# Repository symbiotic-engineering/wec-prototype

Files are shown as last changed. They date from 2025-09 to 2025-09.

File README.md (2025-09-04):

# Wave Energy Converter (WEC) Prototype Control System

## 1. Project Overview
Control system for testing **wave energy converter (WEC) prototypes** using a **Raspberry Pi touchscreen UI** and **Arduino motor control**.  
The system allows real-time interaction with prototypes, including selecting WEC type, adjusting frequency/amplitude, and running tests.

## 2. Components / Hardware
- **Raspberry Pi** – Runs the touchscreen UI  
- **Arduino Mega** – Controls the motor  
- **VESC & VESC Express** – Motor controller and Data Logger  
- **WEC prototypes** – Point Absorber and Oscillating Flap types  
- **Touchscreen** – User interface for control  

## 3. Software
- **Python** – Raspberry Pi GUI and control code (`wec_rpi_gui.py`)  
- **MATLAB** – Hydrodynamic analyses (`PA_buoyancy.m`) 
- **Arduino** – Motor control code (`wec_arduino_motorcontrol.ino`)  
- **VESC logging script** (`log_can.lisp`) – Captures motor data points  

## 4. Folder Structure 
```
WEC-Prototype/
├── Arduino_Mega/
│ └── wec_arduino_motorcontrol.ino # Arduino firmware controlling motor based on RPi commands
├── CAD/
│ └── Multiple CAD pdf files
├── Raspberry_Pi/
│ └── wec_rpi_gui.py # Python UI for controlling WEC tests
└── VESC/
└── log_can.lisp # Logs motor data points during testing
├── hydrodynamics/
  └── PA_buoyancy.m # Evaluates the hydrodynamic repsonse of the PA
├── gear_ratio_appendix/
  └── Files required to simulate both the PA and OSWEC to estimate required GR
```
## 5. Code Setup Instructions

1. **Raspberry Pi**  
   - Copy `wec_rpi_gui.py` to the Pi.  
   - Configure the script to run automatically using **cron**.  
   - Connect Raspberry Pi to Arduino via USB.  

2. **Arduino Mega**  
   - Flash `wec_arduino_motorcontrol.ino` onto the Arduino.  
   - Ensure the **VESC UART library** is downloaded from GitHub and stored in Arduino’s libraries folder.  

3. **VESC / VESC Express**  
   - Flash firmware and edit log_can.lisp to VESC and VESC Express.  

4. **Dependencies & Hardware Connections**  
   - Proper USB connection between Pi and Arduino.  
   - Ensure VESC and motor connections are secure before powering the system.  

## 6. Usage Instructions

1. Power on Raspberry Pi and Arduino.  
2. Start the Python UI (`wec_rpi_gui.py`) via touchscreen or cron.  
3. Select the WEC type (Point Absorber or Oscillating Flap).  
4. Verify that all **electrical connections** are secure.  
5. Run tests by selecting frequency/amplitude options in the UI.  
6. Data from the VESC can be logged using `log_can.lisp`.

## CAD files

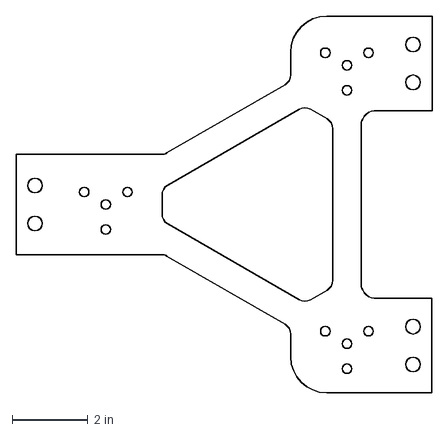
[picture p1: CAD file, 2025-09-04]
CAD/PA_BasePlate.dxf
11.0 x 9.96 in

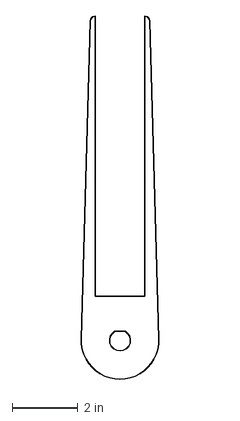
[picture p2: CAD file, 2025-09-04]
CAD/OSWEC_Struts.dxf
2.39 x 11.1 in

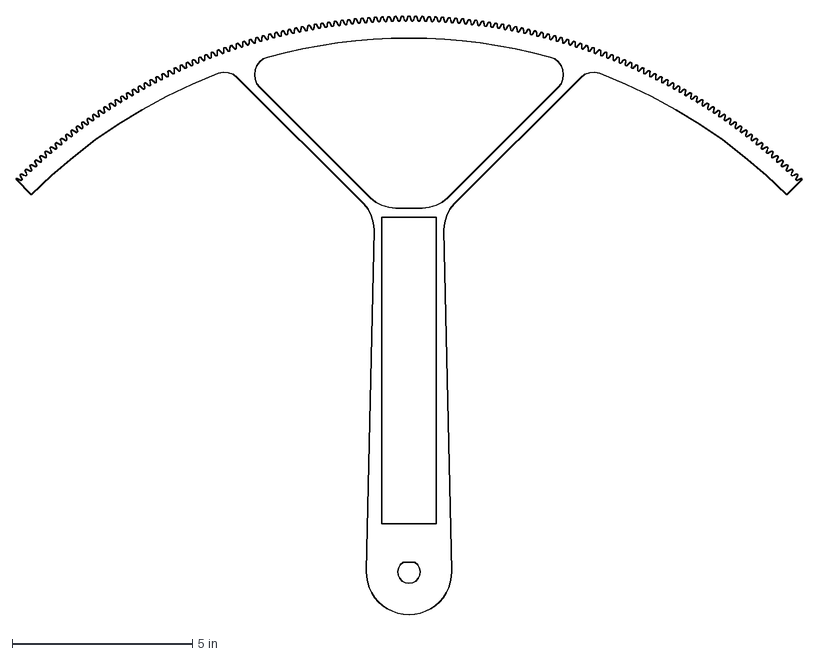
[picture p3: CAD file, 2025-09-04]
CAD/CurvedRack.dxf
21.8 x 16.6 in

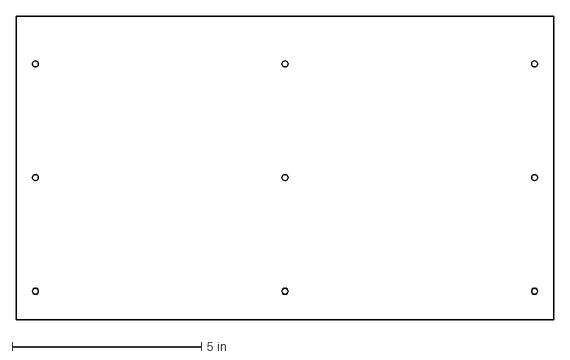
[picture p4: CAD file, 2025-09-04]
CAD/OSWEC_AcrylicPlate.dxf
14.2 x 8.00 in

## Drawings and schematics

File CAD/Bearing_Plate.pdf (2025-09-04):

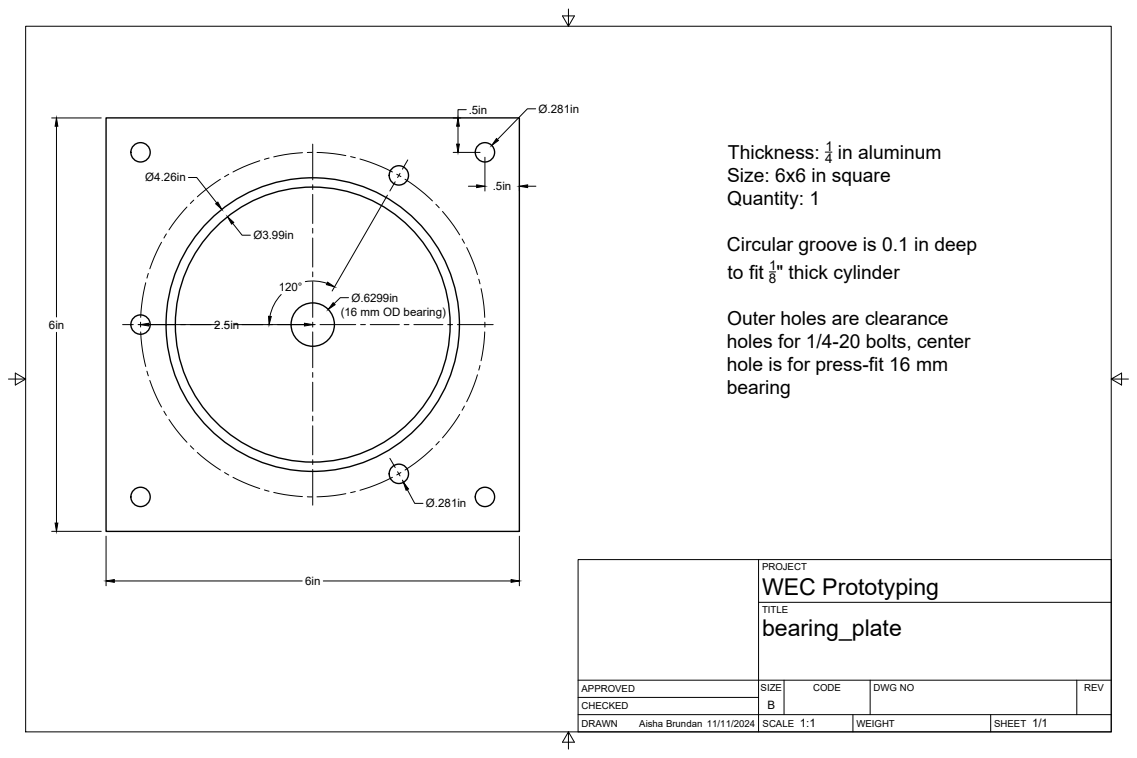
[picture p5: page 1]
SIZE; CODE; DWG NO; REV; Aisha Brundan 11/11/2024; WEC Prototyping; in aluminum

Thickness: 1
Size: 6x6 in square
Quantity: 1

Circular groove is 0.1 in deep
to fit 1
" thick cylinder

(16 mm OD bearing)

Outer holes are clearance
holes for 1/4-20 bolts, center
hole is for press-fit 16 mm
bearing

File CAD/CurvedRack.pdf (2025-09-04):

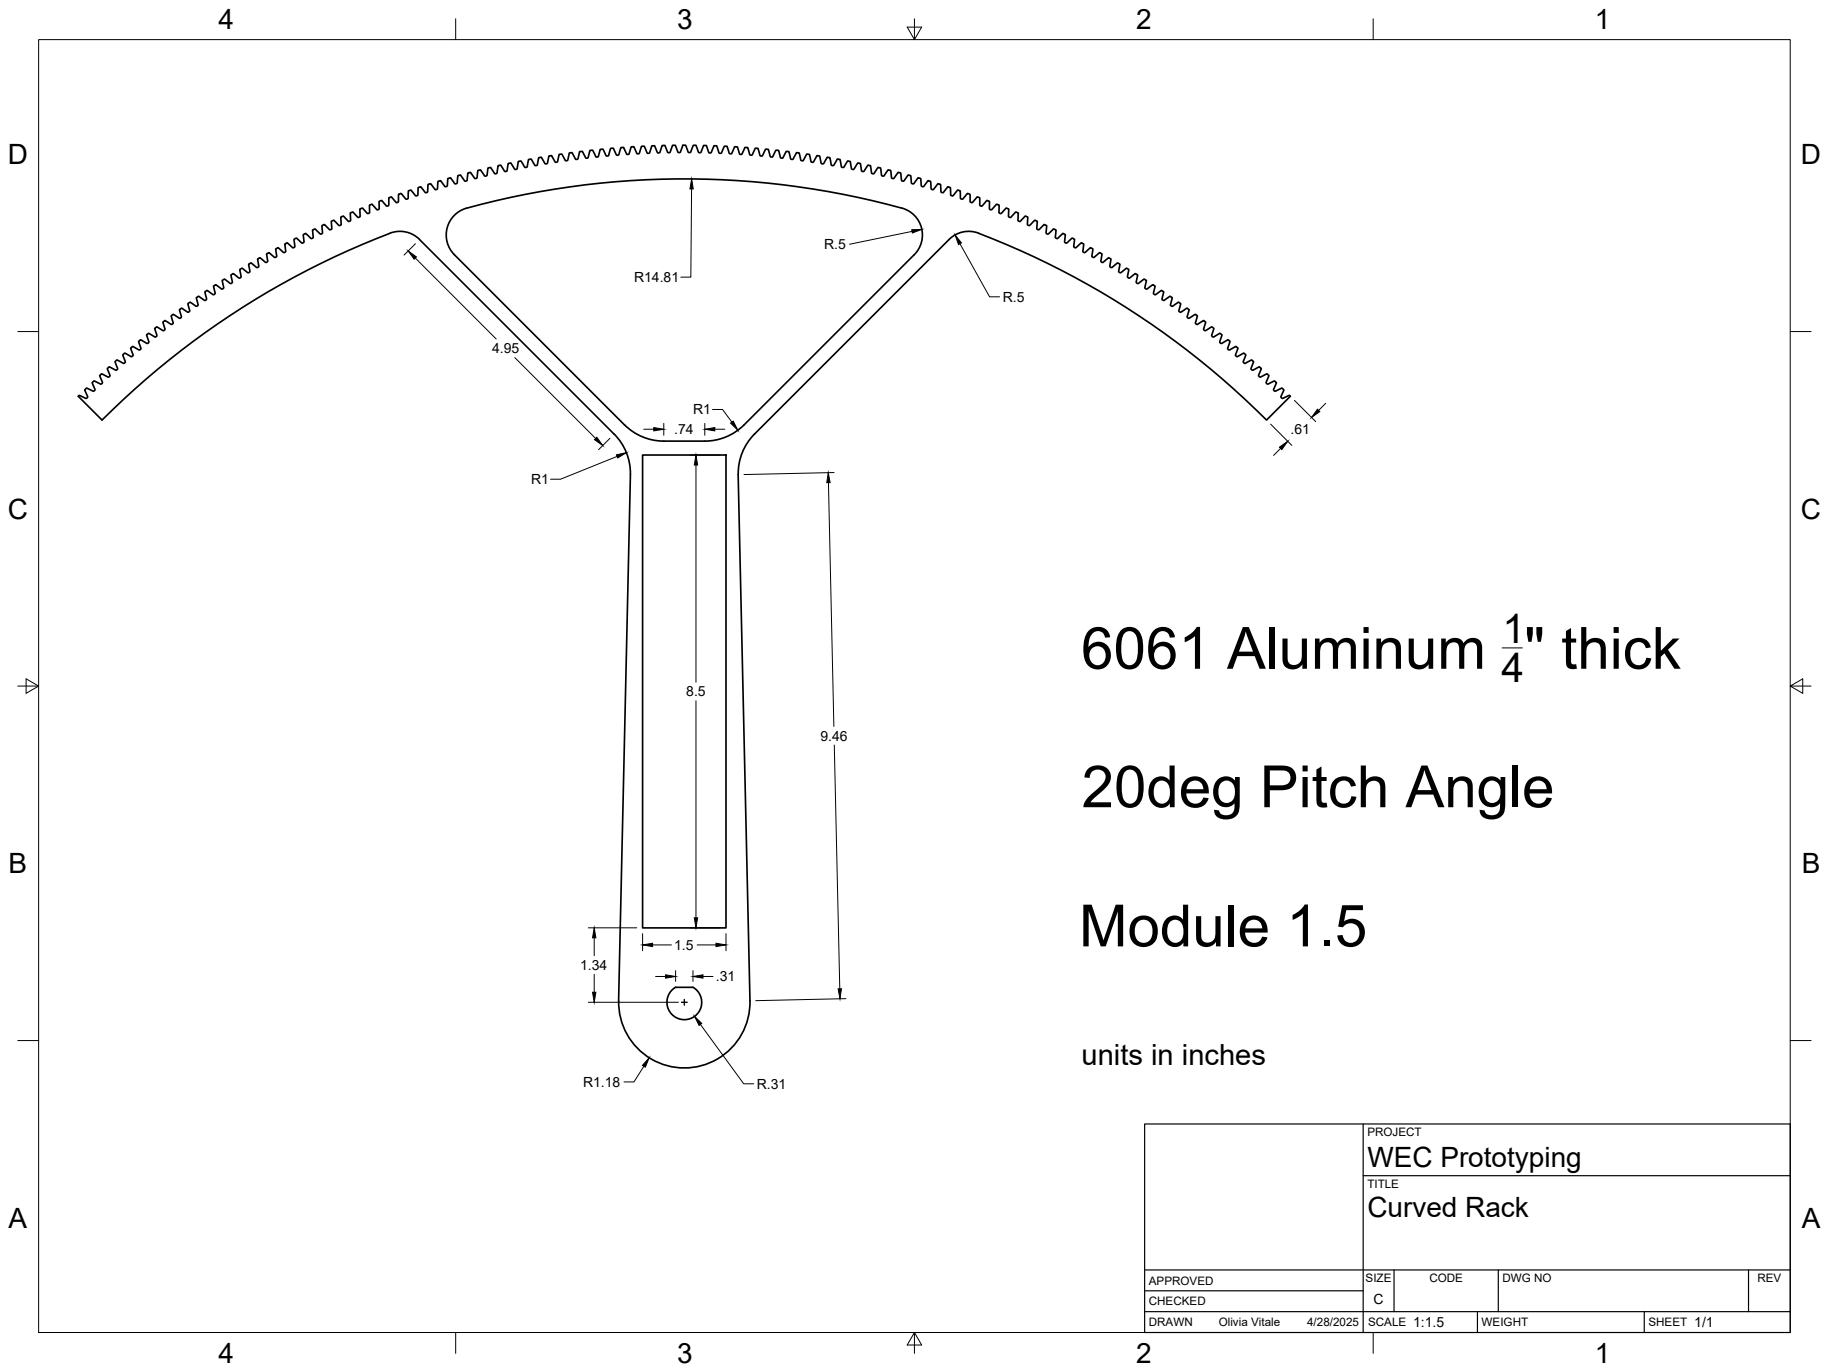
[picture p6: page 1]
SIZE; CODE; DWG NO; REV; Olivia Vitale; WEC Prototyping; Curved Rack; 6061 Aluminum 1 " thick; 20deg Pitch Angle; Module 1.5

units in inches

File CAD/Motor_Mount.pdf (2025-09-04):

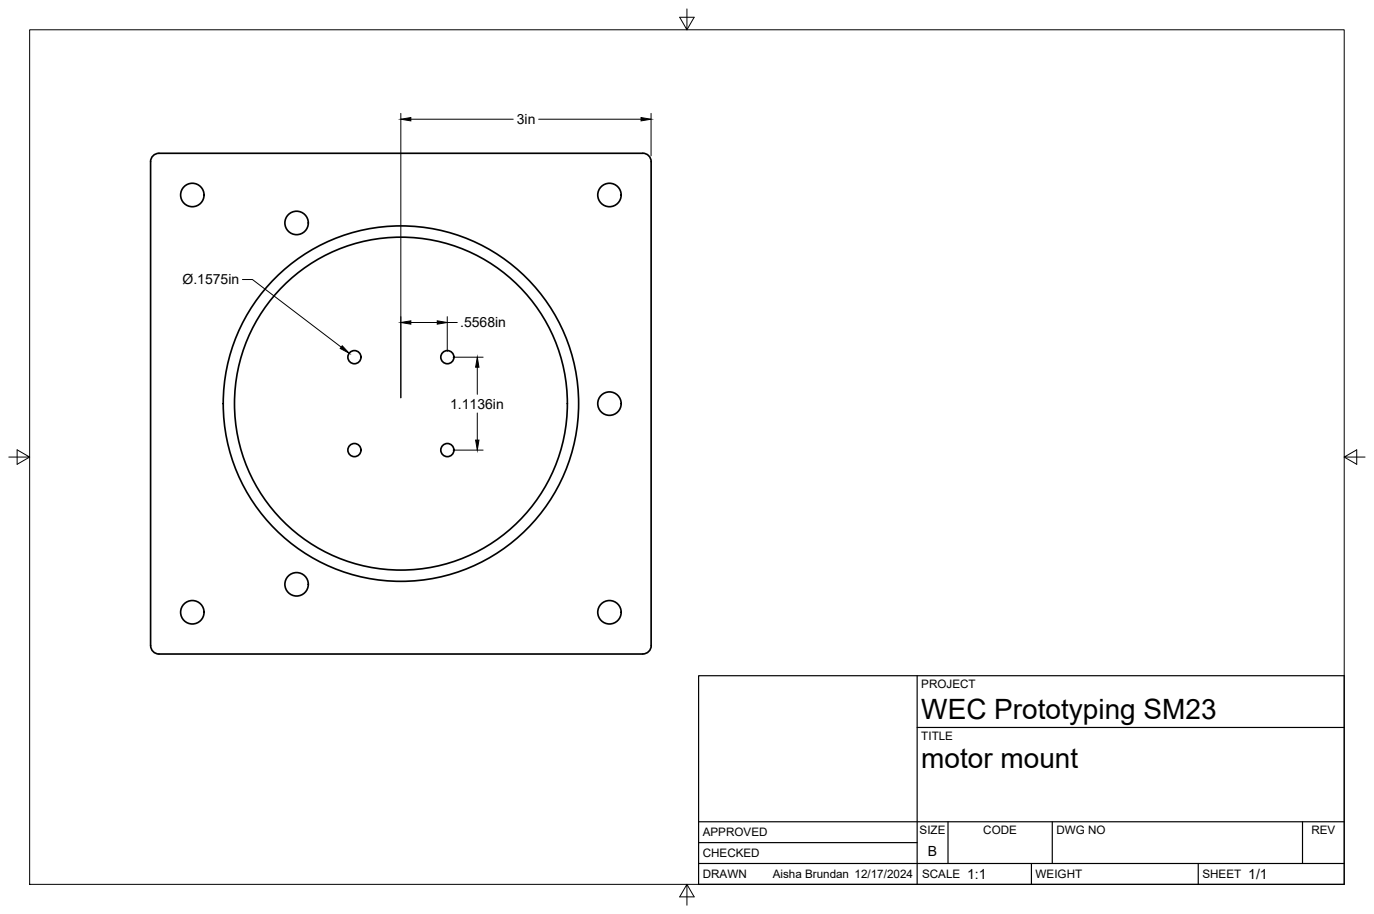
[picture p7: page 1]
SIZE; CODE; DWG NO; REV; Aisha Brundan 12/17/2024; WEC Prototyping SM23; motor mount

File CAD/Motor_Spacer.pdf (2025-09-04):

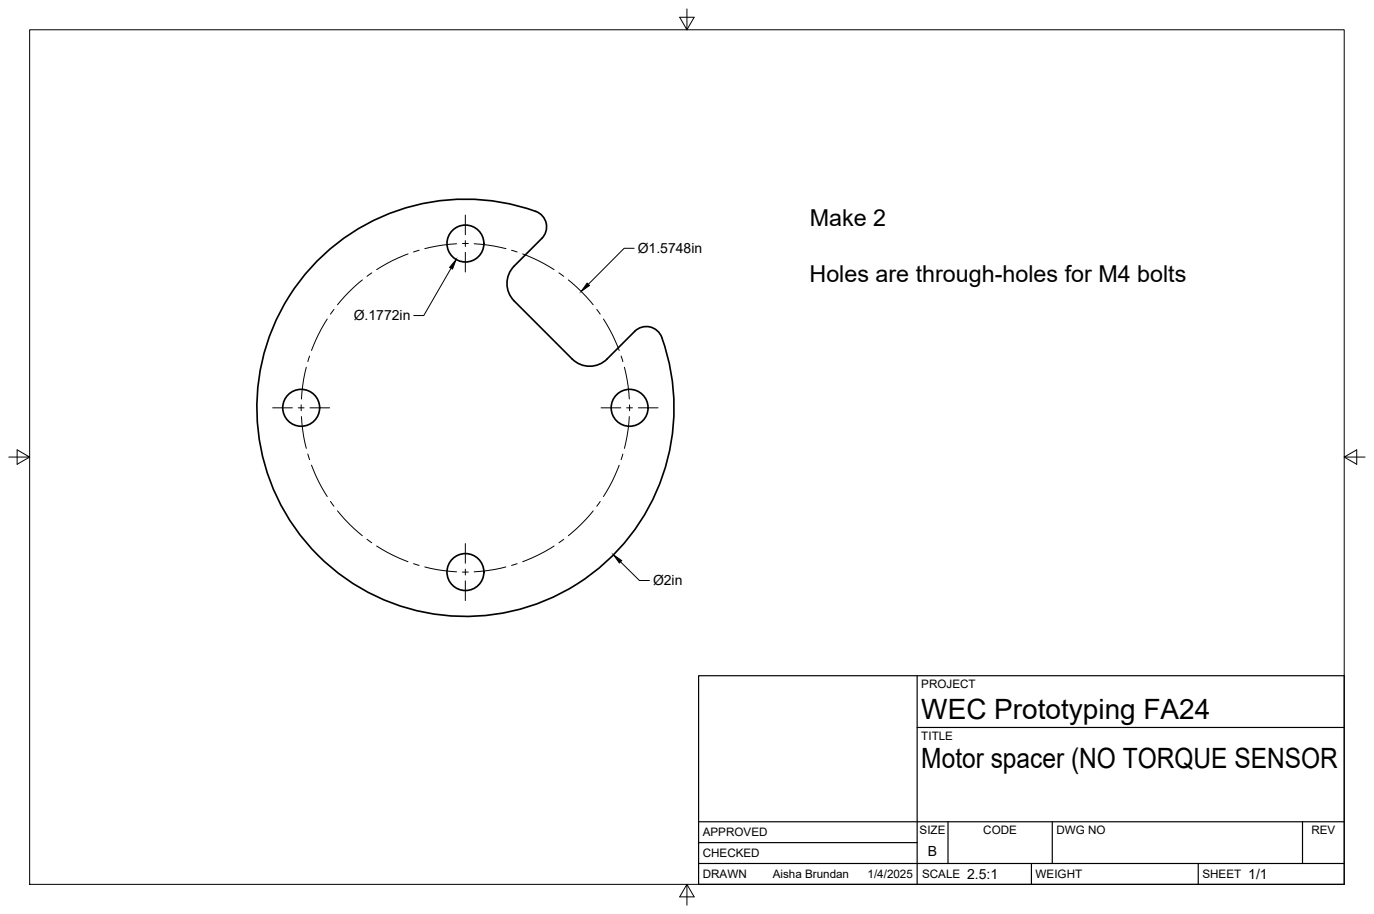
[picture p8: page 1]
SIZE; CODE; DWG NO; REV; Aisha Brundan; Make 2

Holes are through-holes for M4 bolts

PROJECT
WEC Prototyping FA24
Motor spacer (NO TORQUE SENSOR

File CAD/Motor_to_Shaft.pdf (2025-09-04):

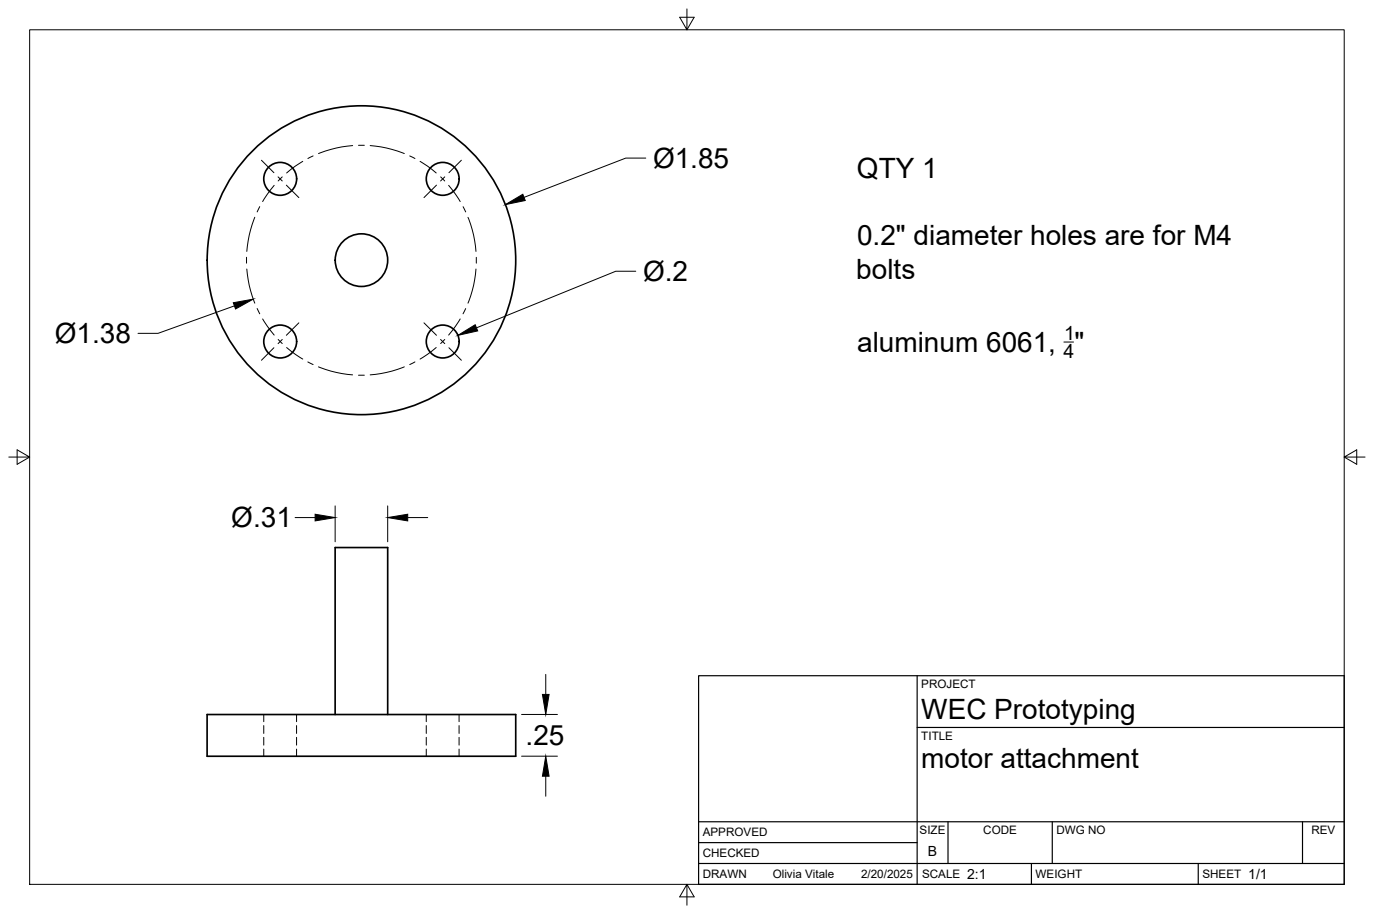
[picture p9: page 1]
SIZE; CODE; DWG NO; REV; Olivia Vitale; WEC Prototyping; motor attachment; QTY 1; aluminum 6061, 1

0.2" diameter holes are for M4
bolts

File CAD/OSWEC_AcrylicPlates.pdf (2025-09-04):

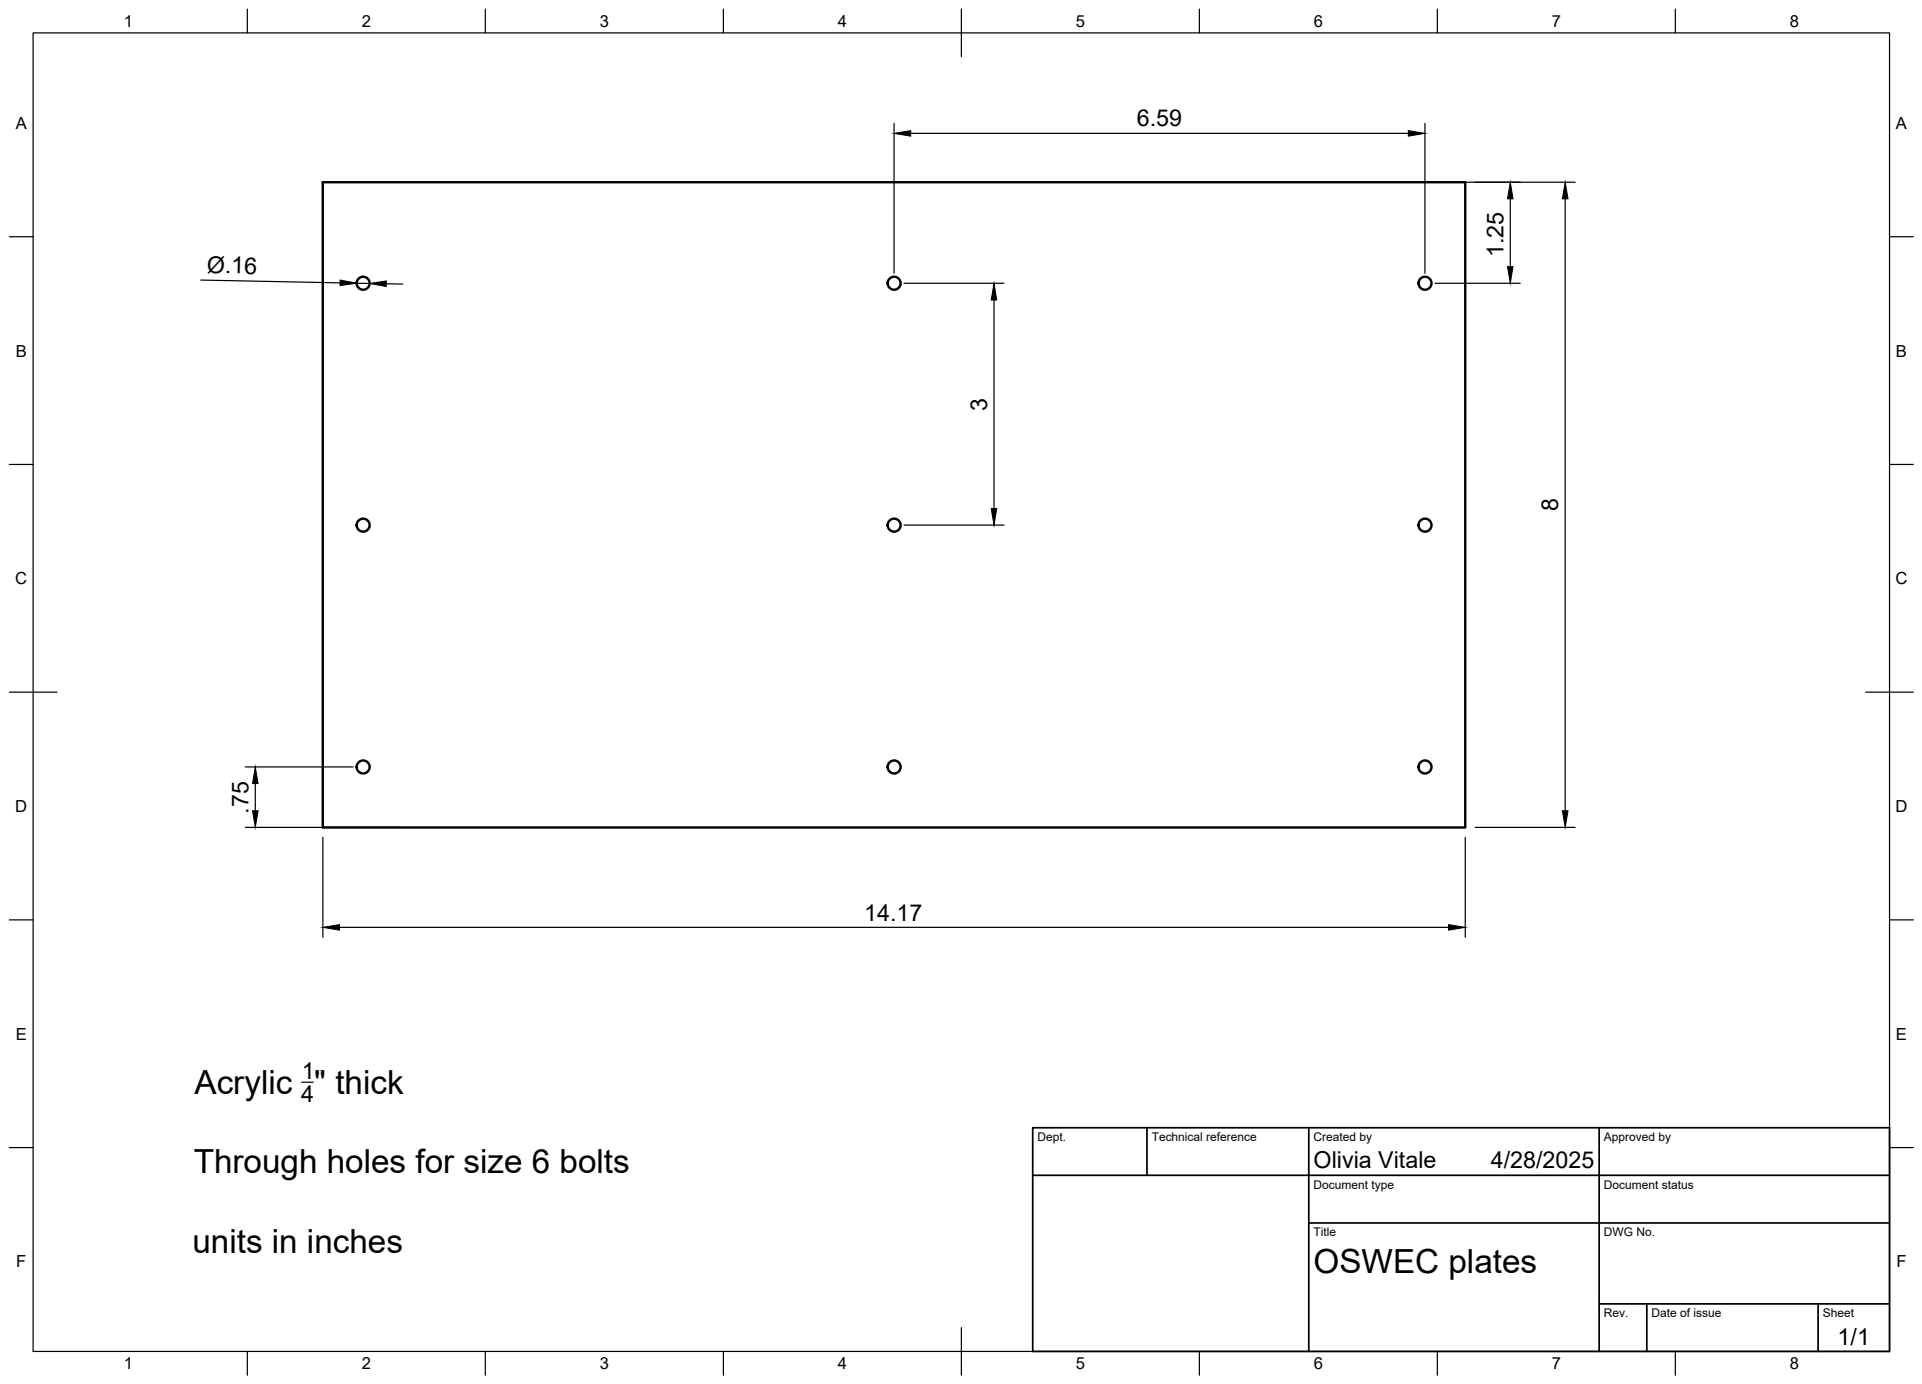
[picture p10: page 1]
Title; DWG No.; Rev.; Date of issue; Sheet; OSWEC plates; Acrylic 1 " thick

Dept. | Technical reference | Created by Olivia Vitale 4/28/2025 | Approved by

Through holes for size 6 bolts

Document type | Document status

units in inches

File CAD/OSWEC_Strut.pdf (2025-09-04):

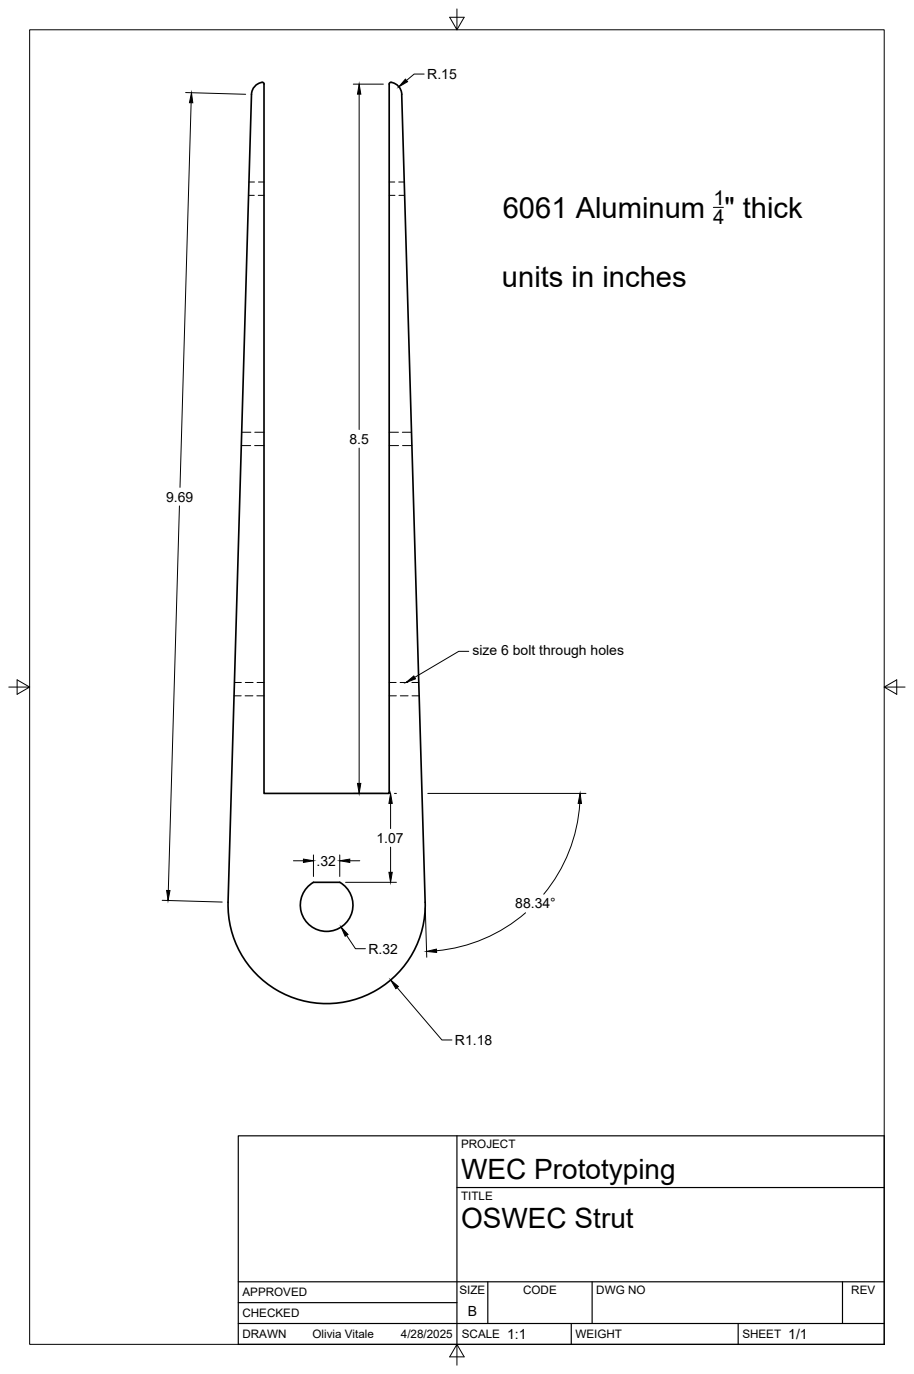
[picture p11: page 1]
SIZE; CODE; DWG NO; REV; Olivia Vitale; WEC Prototyping; OSWEC Strut; 6061 Aluminum 1 " thick

units in inches

size 6 bolt through holes

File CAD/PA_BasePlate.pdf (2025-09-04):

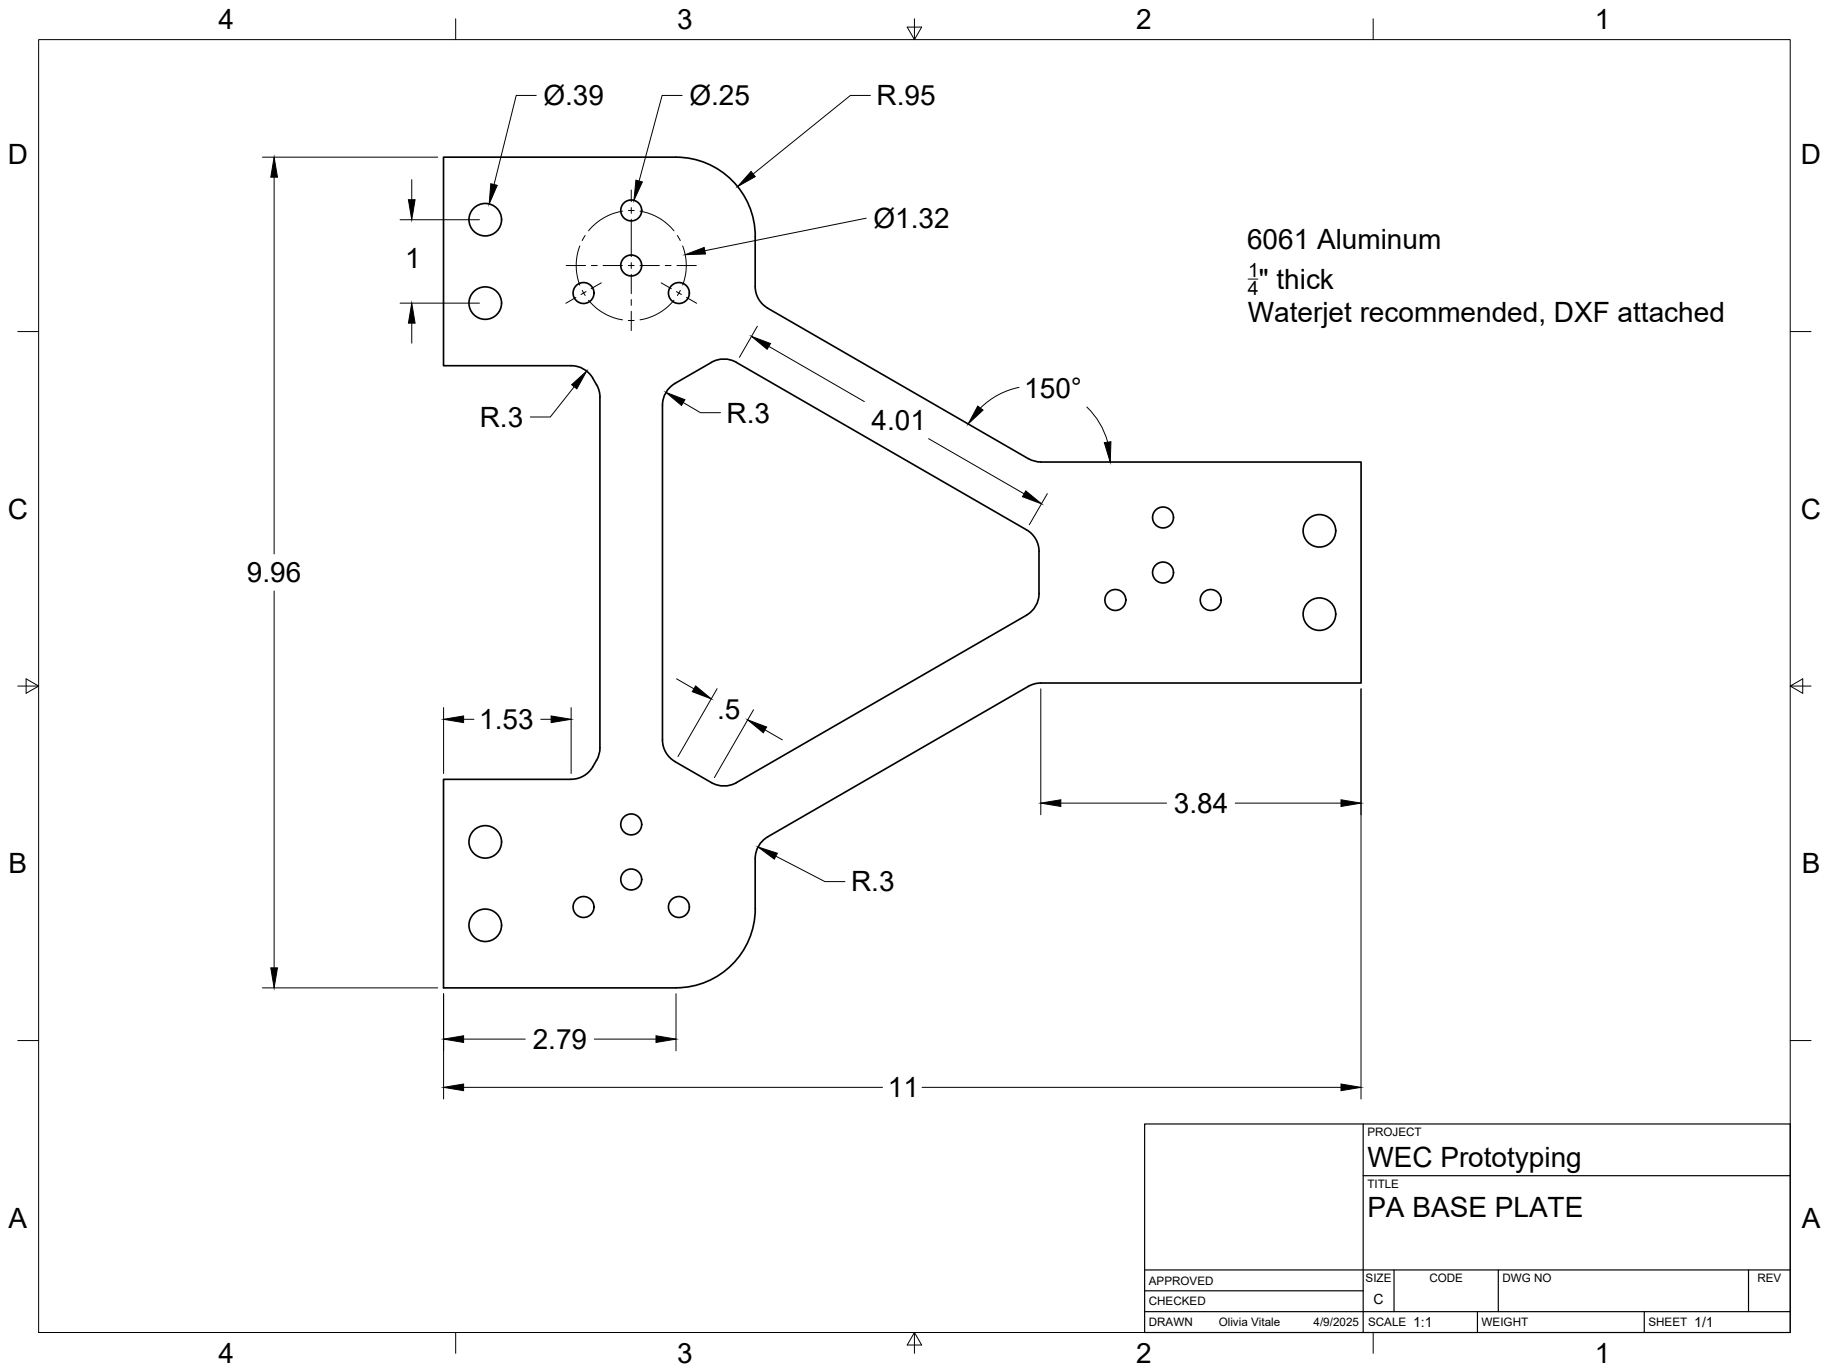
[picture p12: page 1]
SIZE; CODE; DWG NO; REV; Olivia Vitale

6061 Aluminum
1/4" thick
Waterjet recommended, DXF attached

PROJECT
WEC Prototyping
PA BASE PLATE

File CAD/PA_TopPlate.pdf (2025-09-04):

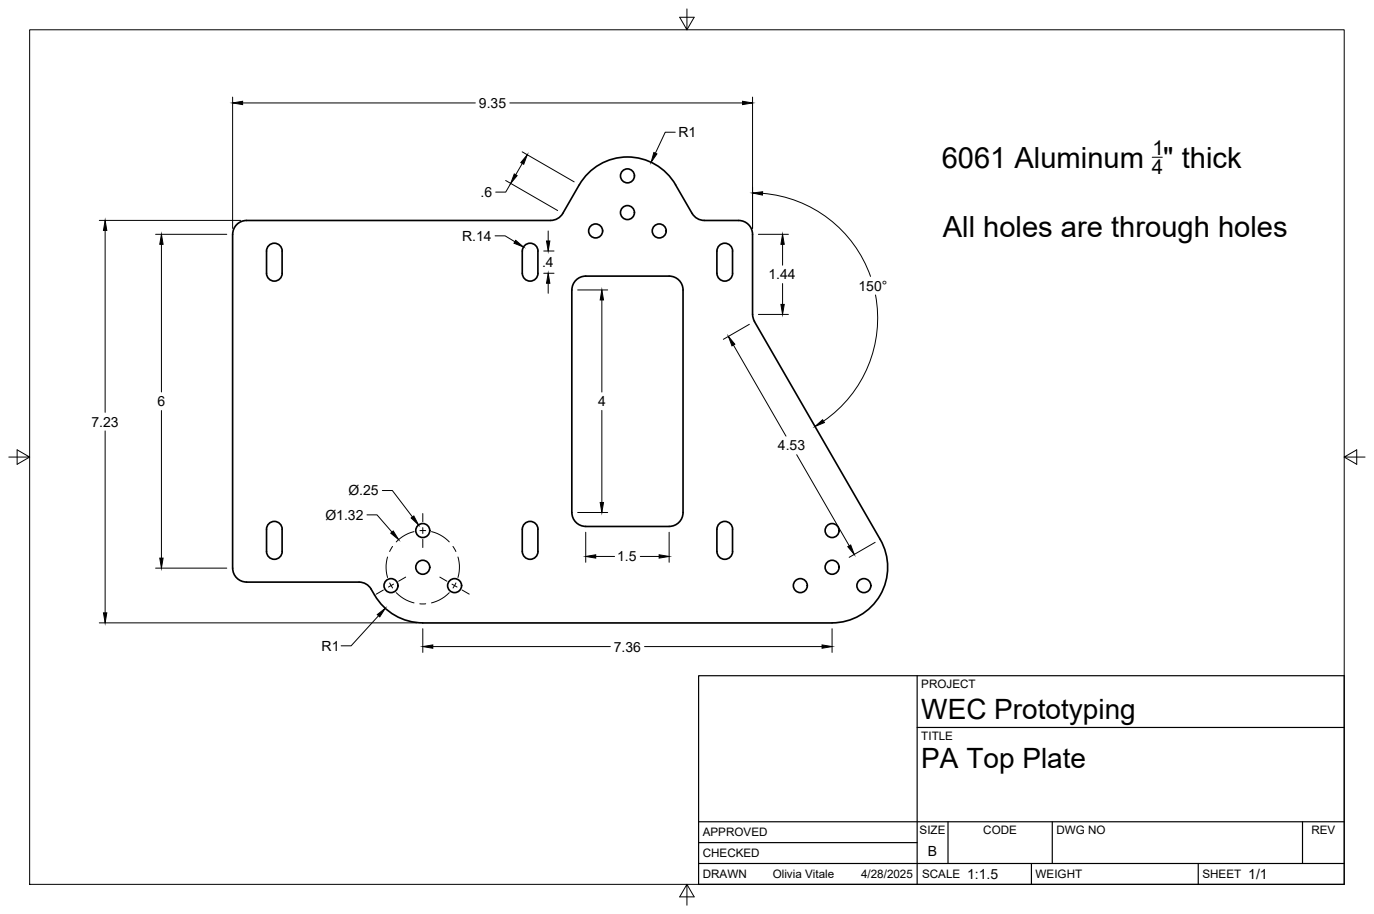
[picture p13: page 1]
SIZE; CODE; DWG NO; REV; Olivia Vitale; 6061 Aluminum 1 " thick

All holes are through holes

PROJECT
WEC Prototyping
PA Top Plate

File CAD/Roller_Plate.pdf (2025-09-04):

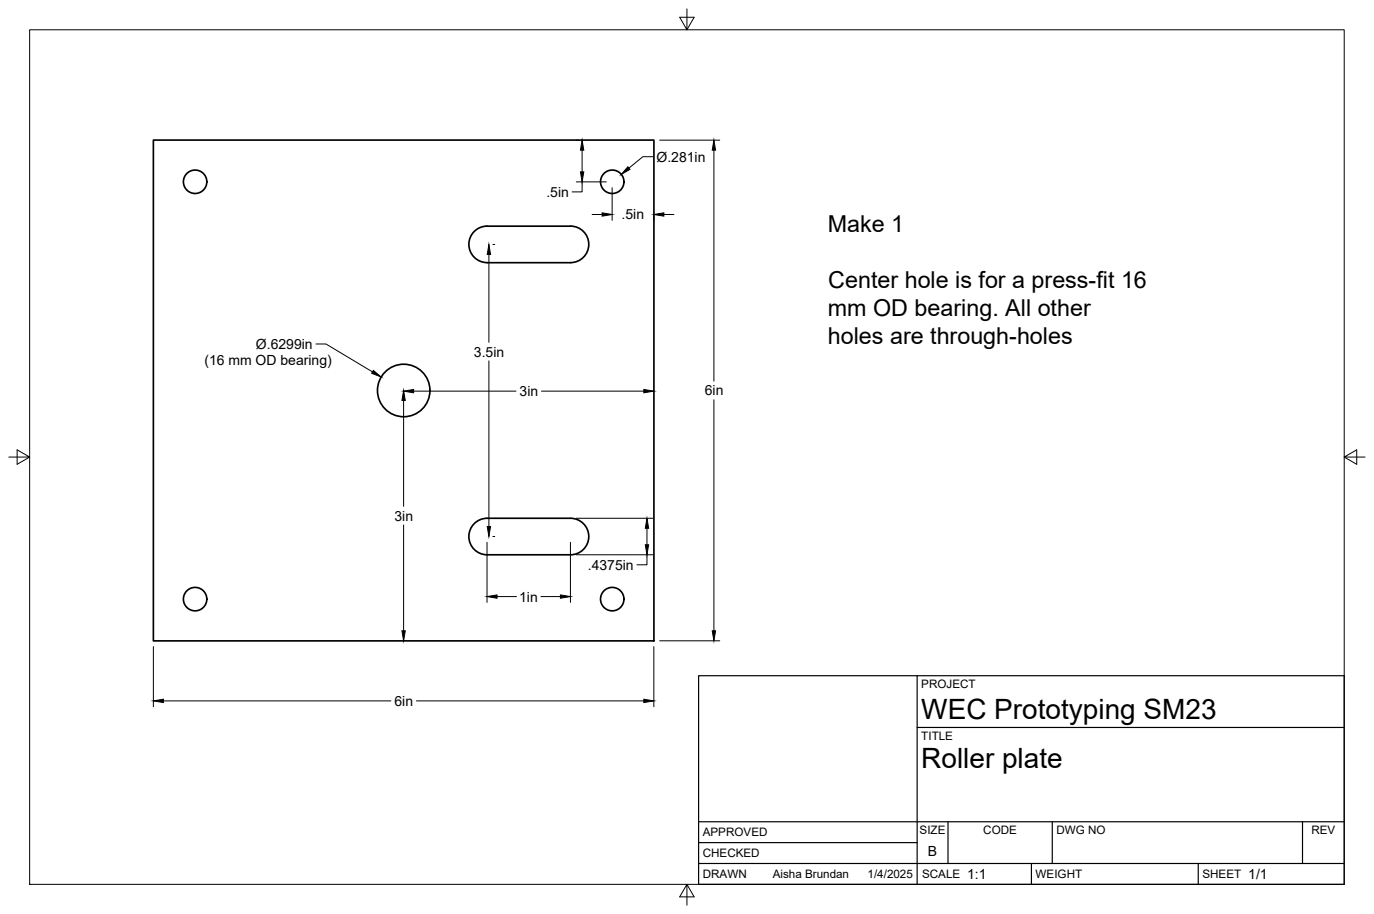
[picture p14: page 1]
SIZE; CODE; DWG NO; REV; Aisha Brundan; WEC Prototyping SM23; Roller plate; Make 1

Center hole is for a press-fit 16
mm OD bearing. All other
holes are through-holes

3.5in (16 mm OD bearing)

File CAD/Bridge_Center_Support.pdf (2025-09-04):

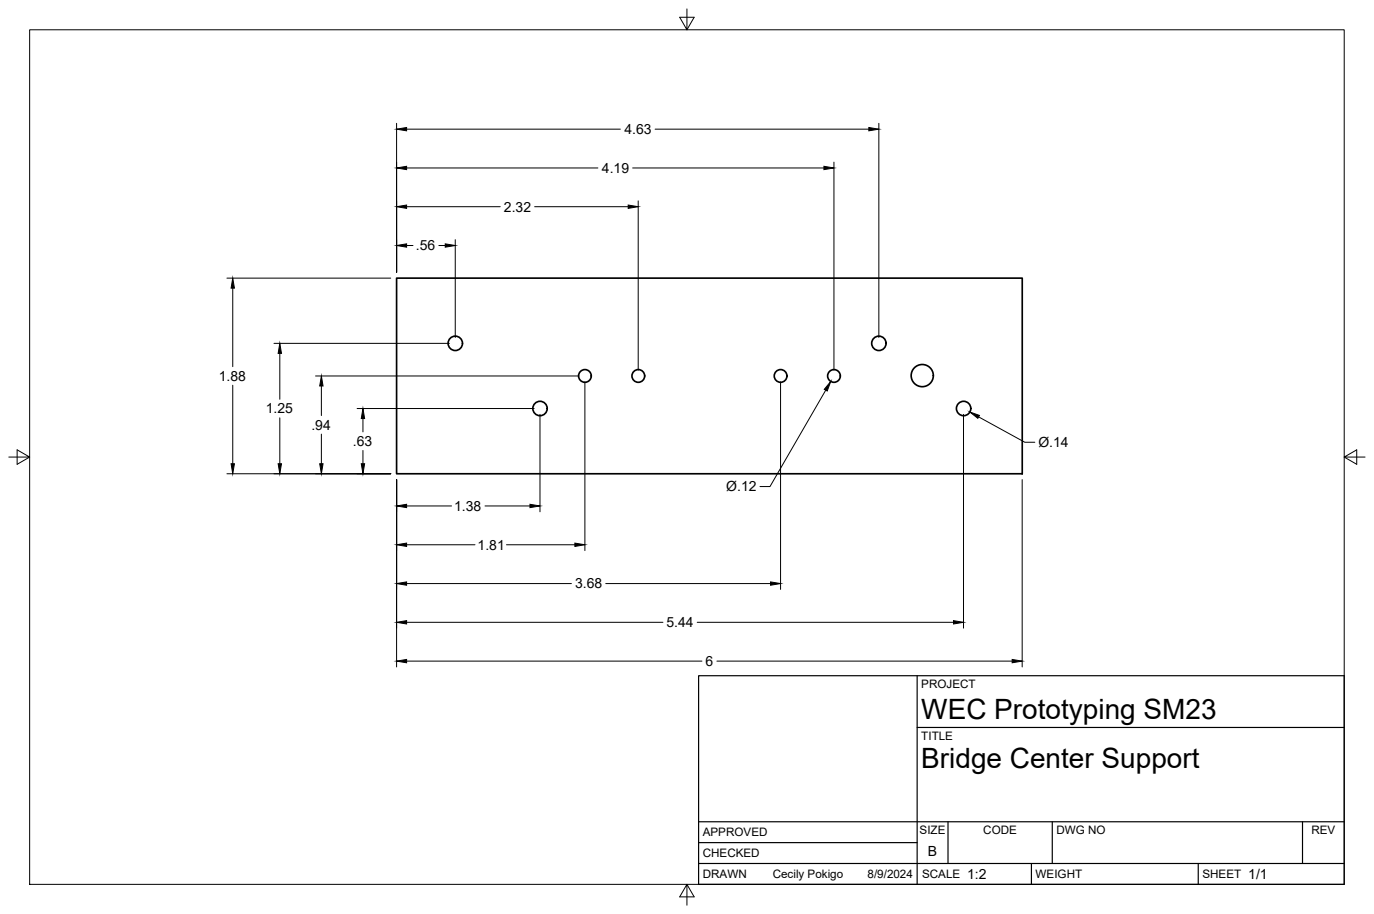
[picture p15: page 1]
SIZE; CODE; DWG NO; REV; Cecily Pokigo

PROJECT
WEC Prototyping SM23
Bridge Center Support

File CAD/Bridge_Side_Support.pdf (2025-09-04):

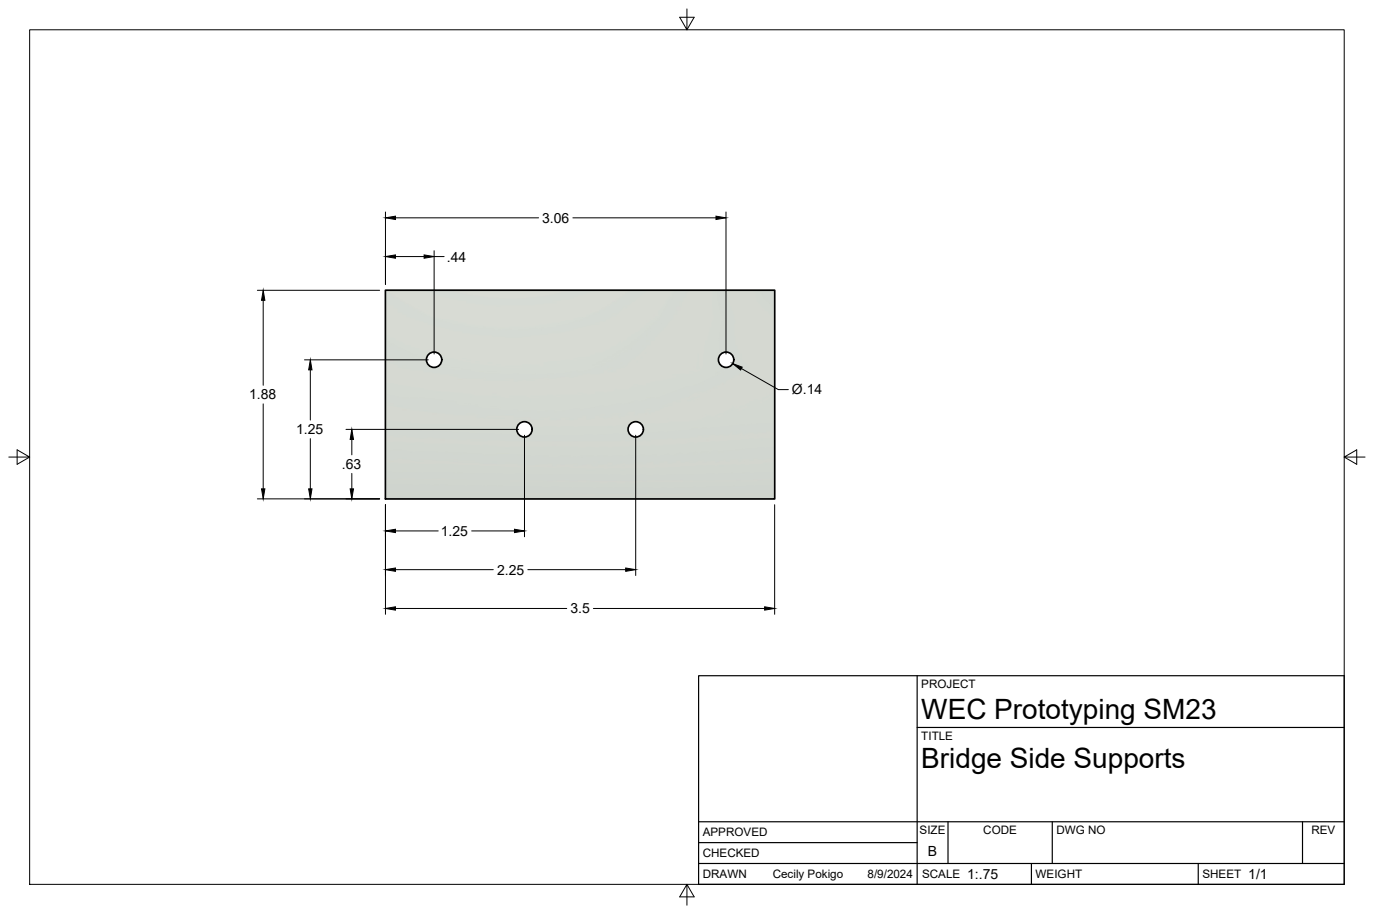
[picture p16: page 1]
SIZE; CODE; DWG NO; REV; Cecily Pokigo

PROJECT
WEC Prototyping SM23
Bridge Side Supports

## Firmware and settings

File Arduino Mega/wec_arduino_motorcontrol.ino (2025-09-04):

#include <VescUart.h>

VescUart UART;

#define gearRatio 26
#define k_b 11.5
#define r_eff 0.026
#define I_thresh 30

// Variables for current calculation 
float v;     //velocity [m/s]
float x;     //amplitude [m]
float bp;  //PTO damping 
float kp;  //PTO stiffness
float M;   //mass [kg] for point absorber, mass moment of inertia [kg-m^2] for osc flap
float K;    //stiffness [N/m]
float A;   //added mass [kg[]
float B;   //radiation damping [kg/s]
volatile float theta = 0; 
float c_speed;

// Variables for Rpi UI info
String message;  //message from Rpi
float frequency;   //frequency value
String wec_type; //wec type (PA ore  OS)
float amp;           //amplitude [m]

int freqIndex;     //index of frequency in message
int ampIndex;    //index of amplitude in message
int typeIndex;    //index of wec type in message

// Variables for Forced Osc Test rpm calculation
float v_set = 14.64;        //velocity [m/s]
float rpm;                //rpm [revs/minute]
float offTime;          //amount of time motor should be off [ms]
float onTime;          //amount of time motor should be on [ms]
float w_motor;        //angular velocity of motor [rad/sec]

//Test variables
float current = 2.10;
bool oscTest;          //bool value for OSC test
bool motorControl; //bool value for motor control

void setup() {
  Serial.begin(115200);
  Serial1.begin(115200);
  while (!Serial1) {;}

  //Set UART comm to VESC to Serial1
  UART.setSerialPort(&Serial1);
  oscTest = 0;
  motorControl = 0;
}

 void parse_message(String message) {

  
  //Get the index of frequency and type
  freqIndex = message.indexOf("Frequency:");
  typeIndex = message.indexOf("Type:");
  ampIndex = message.indexOf("Amp:");

  //If these imdexes exist then start parsing 
  if(freqIndex != -1 && typeIndex != -1){
    //go past the 10 characters in frequency and get the frequency value
    //stop at the delimiter "|"
    //convert the frequency from a string to int  
    frequency = message.substring(freqIndex + 10, message.indexOf("|", freqIndex)).toInt();
    
    //Obtain wec_type from the rest of the message 
    wec_type = message.substring(typeIndex + 5, message.indexOf("|", typeIndex));
    }

   if( ampIndex != -1) {
    //Obtain the amp information 
    amp = message.substring(ampIndex + 4).toFloat();
    }
    //Serial.println(amp);
  }


// note: the following helper function only exists still bc it helps for 
// specifying that we are running a forced osc test
 void calcOscTestRPM(float amp) {
  //calculate time to spin
  onTime = amp/v_set;
  //omega 
  w_motor = v_set/r_eff;
  //time to stay off
  offTime = (1/frequency) * 1000;
  //calculating rpm 
  rpm = w_motor * 9.55;
 }

void set_OscCurrent(String wec_type, double frequency, double amplitude) {
    float multiplier = 1.0;  // Default multiplier
    float time_sec = micros() / 1.0e6;  // Convert microseconds to seconds

    if (wec_type == "PA") {
        multiplier = 800.0;
    } 
    else if (wec_type == "OS") {
        multiplier = 50.0;
    }

    if (fabs(frequency == 0.832));
        frequency = 0.8;
    if (fabs(frequency == 0.719));
        frequency = 0.75;
    if (amplitude == 0.02);
        amplitude = 0.04;

    float current = multiplier * amplitude * sin(2 * PI * frequency * time_sec);

    // Avoid very small floating-point errors affecting output
    if (fabs(current) < 0.001) {
        current = 0.0;
    }

    UART.setCurrent(current);
}

void set_parameters(float frequency, String wec_type) {
    if (wec_type == "PA") {
        M = 5.3; K = 643.7;
        if (frequency == 1)       { A = 5.36;  B = 10.47; }
        else if (frequency == 0.832) { A = 5.65;  B = 9.33; }
        else if (frequency == 0.719) { A = 6.13;  B = 8.081; }
    } 
    else if (wec_type == "OS") {
        M = 0.0082; K = 1636.98;
        if (frequency == 1)       { A = 0.0167; B = 7.35; }
        else if (frequency == 0.832) { A = 0.01676; B = 2.862; }
        else if (frequency == 0.719) { A = 0.0167; B = 1.253; }
    }
    bp = B;
    kp = sqrt(K / (M + A));
}

void calcCurrent(float w_motor, float theta, String wec_type) {

  if(wec_type == "PA"){
    v = w_motor * r_eff;
    x = theta * r_eff;
  }
  else if(wec_type == "OS") {
    v = w_motor * gearRatio;
    x = theta * gearRatio; 
    }
  
  float F_desired = kp*x + bp*v;
  float I_desired = F_desired * r_eff * k_b;

  if(wec_type == "OS") {
    I_desired = F_desired * gearRatio * k_b;
  }

    if(abs(I_desired) > I_thresh) {
    I_desired = 0.0;
    }

  UART.setCurrent(I_desired);
  }

void loop() {
  //Look for serial message from Rpi
  if(Serial.available() > 0) {
          message = Serial.readStringUntil('\n');
  }

  //Stop the motor if the message is "Stop"                                  
  if(UART.getVescValues() && message == "Stop") {
         oscTest = 0;
         motorControl = 0;
         ampIndex = -1;
         freqIndex = -1;
         typeIndex = -1;
         UART.setRPM(0.00);
         UART.setCurrent(0.00);
 }

  //Else parse the message
  else if(message != "Stop" && message){
         parse_message(message);
  }

  //If amplitude is part of the message it is a forced oscillation test
  if(ampIndex != -1) {
        //calculate RPM
        calcOscTestRPM(amp);
        //set OscTest to true
        oscTest = 1; 
   }

  else if(freqIndex != -1 && typeIndex != -1 && ampIndex == -1) {
        motorControl = 1;
   }

   if(oscTest){
    set_OscCurrent(wec_type, frequency, amp);
    }

  if(motorControl) {

      UART.getVescValues();
      theta = 2 * 3.14159 * (UART.data.tachometer/126);
      c_speed = (UART.data.rpm/21)*(3.14159265359/60);

      set_parameters(frequency, wec_type);
      calcCurrent(c_speed, theta, wec_type);
    }
   
  }

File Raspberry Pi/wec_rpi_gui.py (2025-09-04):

import pygame,pigame
from pygame.locals import *
import os
import sys
from time import sleep
import RPi.GPIO as GPIO
import time
import serial
#Colours
WHITE = (255,255,255)

#setup touchscreen
os.putenv('SDL_VIDEODRV','fbcon')
os.putenv('SDL_FBDEV', '/dev/fb1')
os.putenv('SDL_MOUSEDRV','dummy')
os.putenv('SDL_MOUSEDEV','/dev/null')
os.putenv('DISPLAY','')

#Setting up serial comm
ser = serial.Serial('/dev/ttyACM0', 115200, timeout=1.0)
time.sleep(3)
ser.reset_input_buffer()
print("Serial OK")

#setup pitft screen 
pygame.init()
pitft = pigame.PiTft()
lcd = pygame.display.set_mode((320, 240))
lcd.fill((0,0,0))
pygame.display.update()

#initialize callback for bail out button 
not_ended=True
def quit_callback(channel):
    global not_ended
    not_ended=False
    
#initialize variables for two_collide
size = width, height  =320,240
speed =[3,3]
speed2 =[1,-1]
black =0,0,0

#initialize GPIO callback
GPIO.setup(27,GPIO.IN, pull_up_down=GPIO.PUD_UP)
GPIO.add_event_detect(27, GPIO.FALLING,quit_callback)
     
#intialize font, and sets of buttons to be displayed on the screen
font_big = pygame.font.Font(None, 30)
touch_buttons = {'Start':(30,220),'Stop':(280,220), 'Osc. Test': (160,220), 'Frequency:': (60,20), '1':(140,20), '0.832':(200,20), '0.719':(290,20),
                 'WEC:': (30,80), 'Osc. Flap': (120, 80), 'Point Abs.':(260,80),
                 'Amp:': (30,120), '0.02': (90, 120), '0.06':(160,120), '0.1':(240,120)}
for k,v in touch_buttons.items():
    text_surface = font_big.render('%s'%k, True, WHITE)
    rect = text_surface.get_rect(center=v)
    lcd.blit(text_surface, rect)

#initialize variable to see if two collide is being displayed
started= False
continued = False
stopped=False

clock = pygame.time.Clock()
FPS = 30
clock.tick(FPS)
pygame.display.update()

def send_test_command(frequency, wec_type, amp):
    message = f"Frequency:{frequency}|Type:{wec_type}|Amp:{amp}\n"
    ser.write(message.encode('utf-8'))

def send_command(frequency, wec_type):
    message = f"Frequency:{frequency}|Type:{wec_type}\n"
    ser.write(message.encode('utf-8'))
    
#initialize start time 
start_time=time.time()
try:
    #automatically quit if the it has been 60 seconds or bail out button pressed 
    while not_ended:
        pitft.update()
        #update framerate
        clock.tick(FPS)
         
        # Scan touchscreen events
        for event in pygame.event.get():
            sleep(0.1)
            clock.tick(FPS)
            if(event.type is MOUSEBUTTONDOWN):
                x,y = pygame.mouse.get_pos()
                print(x,y)
            elif(event.type is MOUSEBUTTONUP):
                #update display with the right buttons 
                lcd.fill((0,0,0))
                for k,v in touch_buttons.items():
                    text_surface = font_big.render('%s'%k, True, WHITE)
                    rect = text_surface.get_rect(center=v)
                    lcd.blit(text_surface, rect)
                x,y = pygame.mouse.get_pos()
                
                #Start, Stop and Test touch detection  
                if(x>280 and y>210):
                    stopped=True
                    started=False
                elif (x<30 and y>210):
                    started=True
                    stopped=False
                elif(130<x<210 and y>210):
                    print("Test")
                    continued = True
                    stopped = False
                    send_test_command(frequency, wec_type, amp)
                
                #Frequency touch detection 
                elif(130<x<200 and y<30):
                    print("Frequency 1")
                    frequency = 1
                elif(210<x<280 and y<30):
                    print("Frequency 0.832")
                    frequency = 0.832
                elif(x>296 and y<30):
                    print("Frequency 0.719")
                    frequency = 0.719
                
                #WEC type selection
                elif(90<x<160 and 60<y<90):
                    print("Osc WEC")
                    wec_type = "OS"
                elif(230<x and 60<y<90):
                    print("Point Abs")
                    wec_type = "PA"  
                    
                #Amplitude detection   
                elif(80<x<130 and y<130):
                    print("amp 0.02")
                    amp = 0.02
                elif(150<x<210 and y<130):
                    print("amp 0.06")
                    amp = 0.06
                elif(x>230 and y<130):
                    print("amp 0.1")
                    amp = 0.1
                
                #Start and Stop
                if(started and not continued):
                    print("Started")
                    send_command(frequency, wec_type)
                    continued = True
                elif(stopped and continued):
                    print("Stopped")
                    ser.write("Stop\n".encode('utf-8'))
                    continued = False
                    
                print(x,y)
                        
        #yield the thread for callbacks 
        sleep(0.000001)
except KeyboardInterrupt:
    pass
finally:
    del(pitft)

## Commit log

2023-10-10 Upload Nelsons PCB files from last semester
    [mecc-pcb-kicad-B_Cu.gbl, mecc-pcb-kicad-B_Mask.gbs, mecc-pcb-kicad-B_Silkscreen.gbo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]
2023-10-10 Create sensor-board-connection-list
    This file lists what the sensor board connects to
2023-10-10 Update sensor-board-connection-list
2024-05-14 olivias changes to run oswec real hydro data and sweep spring and GR
2024-06-11 move to folder so arduino ide can open files
2024-07-03 clean up hydro coeffs, add motor torque output, and make work for rm3 too
2024-09-10 add wave height sweep and ability to sim RM5 without string-spring
2024-09-10 fix lines on graph for single spring size
2024-09-10 lower the torque for radiation test to get it unstuck
2024-10-01 changes to state machine code to send microcontroller back to boot once powered down
2024-10-01 updated to print actual battery voltage
2025-08-27 Update wec_arduino_motorcontrol.ino
    Final motor controls code that runs on the Arduino Mega.
2025-08-27 Create log_can.lisp
    .lisp that controls the data points logged by the VESC. Note that this script must be the exact same in both the VESC and VESC Express to perform proper logging
2025-08-28 added gear ratio scripts to jmd branch
2025-09-04 fixed these calculations and plots
    [CurvedRack.dxf, OSWEC_Struts.dxf, PA_BasePlate.dxf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]
